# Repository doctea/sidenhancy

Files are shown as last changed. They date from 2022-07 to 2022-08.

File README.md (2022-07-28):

# sidenhancy

- Eurorack module based around the ARMSID SID chip clone
- Based around Atmega 1284p
 - oled display and rotary encoder options
 - CV inputs assignable to SID parameters
- Using [mymenu](https://github.com/doctea/mymenu) and [parameters](https://github.com/doctea/parameters)

## Hardware/PCB

- See [Wiring.md](Wiring.md) for pin wiring (unchecked / incomplete / untested!!)
- Note that **PCB FILES in pcb/ ARE NOT FINISHED, DO NOT USE THESE YET!!**

## Todo

- Parameters
  - Oscillator 1/root pitch
  - Oscillator 2 pitch
  - Oscillator 3 pitch
  - Oscillator 1 waveforms selectable 
  - Oscillator 2 waveforms selectable 
  - Oscillator 3 waveforms selectable 
  - Oscillator 1 Pulse width
  - Oscillator 2 Pulse width
  - Oscillator 3 Pulse width
  - Oscillator Detune
  - Chord
  - Filter on/off for oscillator 1
  - Filter on/off for oscillator 2
  - Filter on/off for oscillator 3
  - Filter modes LP / BP / HP
  - Filter cutoff
  - Pitch Quantization settings
- Use SID ADSR?
  - optional so module can just be used as an oscillator
  - otherwise have ADSR for each oscillator be configurable?
- ~~Menu system (using https://github.com/doctea/mymenu)~~
 - ~~Input via rotary encoder + buttons~~
   - (unreliably working with straight encoder)
   - ~~todo: i2c rotary encoder~~
 - ~~System to map assignable inputs to parameters~~
- ~~Display via i2c ss_oled~~
- CV inputs
  - Pitch
    - (working for 0-5v, quantised and not)
    - Make work with 2xPimoroni 24v ADS1015 breakouts
    - tuning / calibration functions
    - ~~three of them, one for each oscillator?~~
    - pitch modulation
    - portamento/glide
  - Filter cutoff
  - Assignable input?
- internal LFOs?
- MIDI input
- Circuit
  - Schematic
    - in progress in pcb/
  - PCB
    - in progress in pcb/
- Panel

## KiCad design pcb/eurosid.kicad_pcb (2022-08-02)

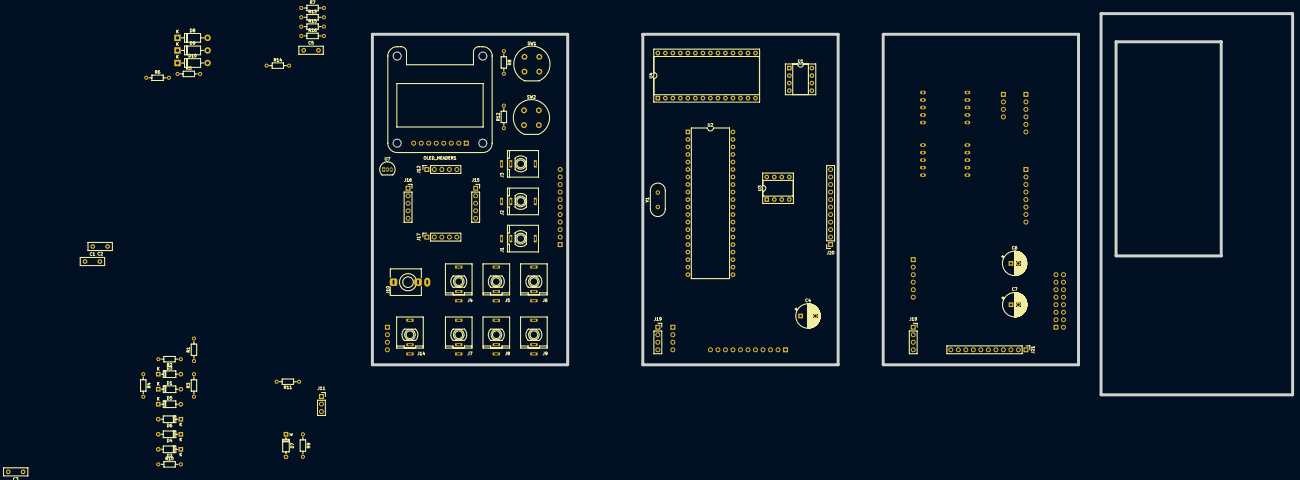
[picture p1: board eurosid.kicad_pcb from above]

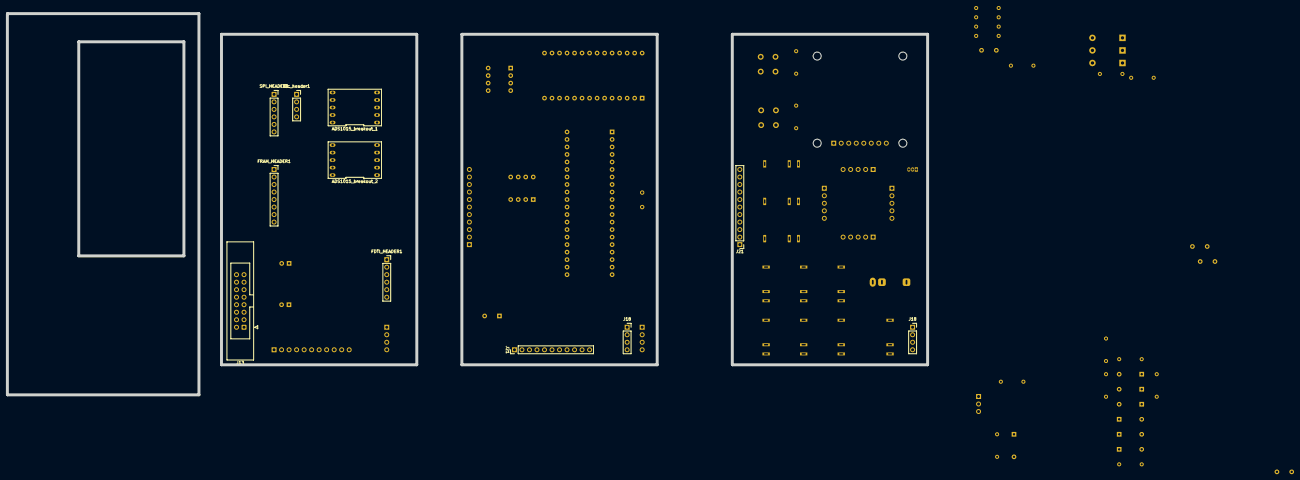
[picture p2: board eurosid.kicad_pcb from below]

Board: 2 copper layers, 311.1 x 128.9 mm, 73 parts (11 on the bottom side), 65 nets, no tracks yet.

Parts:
ADS1015_breakout_1: ADS1015_breakout
ADS1015_breakout_2: ADS1015_breakout_2; ADS1015_breakout
C1, C2: 22pf; C_Disc_D8.0mm_W2.5mm_P5.00mm
C3: 0.1uf; C_Disc_D8.0mm_W2.5mm_P5.00mm
C4: 1uf; CP_Radial_D8.0mm_P5.00mm
C5: 1nf; C_Disc_D8.0mm_W2.5mm_P5.00mm
C6, C7: CP; CP_Radial_D8.0mm_P2.50mm
D1, D2, D3, D4, D5, D6: D_Schottky; D_DO-35_SOD27_P7.62mm_Horizontal
D7: 1N4148; D_DO-35_SOD27_P7.62mm_Horizontal
D8, D9, D10: 1N5817; D_DO-41_SOD81_P10.16mm_Horizontal
FDTI_HEADER1: Conn_01x06_Female; PinSocket_1x06_P2.54mm_Vertical
FRAM_HEADER1: FRAM_Breakout_i2c_01x08; PinSocket_1x08_P2.54mm_Vertical
J1: Gate 1 In; thonkiconn_fuzzySi
J2: Gate 2 In; thonkiconn_fuzzySi
J3: Gate 3 In; thonkiconn_fuzzySi
J4: Input_Jack_A; thonkiconn_fuzzySi
J5: Input_Jack_B; thonkiconn_fuzzySi
J6: Input_Jack_C; thonkiconn_fuzzySi
J7: Input_Jack_D; thonkiconn_fuzzySi
J8: Input_Jack_E; thonkiconn_fuzzySi
J9: Input_Jack_F; thonkiconn_fuzzySi
J10: Stereo jack - MiDI TRS; Jack_3.5mm_QingPu_WQP-PJ366ST_Vertical
J11: MIDI IN Conn_01x03_Male; PinSocket_1x03_P2.54mm_Vertical
J12, J15, J16, J17: i2c encoder; PinSocket_1x05_P2.54mm_Vertical
J13: Euro power; IDC-Header_2x08_P2.54mm_Latch_Vertical
J14: Audio Out Jack; thonkiconn_fuzzySi
J18, J18#2, J19, J19#2: i2c_header_2; PinSocket_1x04_P2.54mm_Vertical
J20: Conn_01x11_Female; PinSocket_1x11_P2.54mm_Vertical
J21, J21#2, J21#3: Conn_01x11_Male; PinHeader_1x11_P2.54mm_Vertical
OLED_HEADER1: SSD1306_i2c_Oled_Conn; Adafruit_SSD1306
R1, R2, R3, R4, R5, R6, R14: 10k; R_Axial_DIN0204_L3.6mm_D1.6mm_P7.62mm_Horizontal
R7: 100k; R_Axial_DIN0204_L3.6mm_D1.6mm_P7.62mm_Horizontal
R8, R12: R; R_Axial_DIN0204_L3.6mm_D1.6mm_P7.62mm_Horizontal
R9, R11: 220R; R_Axial_DIN0204_L3.6mm_D1.6mm_P7.62mm_Horizontal
R10: 4.7K; R_Axial_DIN0204_L3.6mm_D1.6mm_P7.62mm_Horizontal
R13: 220k; R_Axial_DIN0204_L3.6mm_D1.6mm_P7.62mm_Horizontal
R15, R16: 22; R_Axial_DIN0204_L3.6mm_D1.6mm_P7.62mm_Horizontal
SPI_HEADER1: Conn_01x06_Female; PinSocket_1x06_P2.54mm_Vertical
SW1, SW2: SW_Push_Dual; Push_E-Switch_KS01Q01
U1: 6N138; DIP-8_W7.62mm_Socket
U2: ATmega1284-PU; DIP-40_W15.24mm
U3: TL072; DIP-8_W7.62mm_Socket
U4: MOS6581_6582_8580SID; DIP-28_W15.24mm_Socket
U7: L78L33_TO92; TO-92_Inline
Y1: Crystal; Crystal_HC18-U_Vertical
i2c_header1: i2c_spare; PinSocket_1x04_P2.54mm_Vertical

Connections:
3.3v: OLED_HEADER1.1, U7.1
+5V: ADS1015_breakout_1.1, ADS1015_breakout_1.6, ADS1015_breakout_2.1, ADS1015_breakout_2.6, D1.1, D3.1, D5.1, D10.1, FDTI_HEADER1.4, FRAM_HEADER1.8, J12.2, J15.2, J16.2, J17.2, J18.4, J18#2.4, J19.4, J19#2.4, R4.1, R8.2, R11.2, R12.2, SPI_HEADER1.1, U1.8, U2.10, U2.30, U2.32, U4.25, U4.28, U7.3, i2c_header1.1
+12V: C7.1, R16.2, U3.8
-12V: C6.2, R15.2
BUTTON_A: R8.1, SW1.3, U2.29
BUTTON_B: R12.1, SW2.3, U2.28
GND: ADS1015_breakout_1.5, ADS1015_breakout_1.10, ADS1015_breakout_2.5, ADS1015_breakout_2.10, C1.1, C2.2, C5.1, C6.1, C7.2, D2.2, D4.2, D6.2, FDTI_HEADER1.6, FRAM_HEADER1.7, J1.1, J1.2, J2.1, J2.2, J3.1, J3.2, J4.1, J4.2, J5.1, J5.2, J6.1, J6.2, J7.1, J7.2, J8.1, J8.2, J9.1, J9.2, J10.S, J11.1, J12.1, J13.3, J13.4, J13.5, J13.6, J13.7, J13.8, J14.1, J14.2, J15.1, J16.1, J17.1, J18.3, J18#2.3, J19.3, J19#2.3, J20.11, J21.11, J21#2.11, J21#3.11, OLED_HEADER1.2, R5.1, R6.1, R7.2, R10.1, SPI_HEADER1.2, SW1.4, SW2.4, U1.5, U2.11, U2.31, U4.14, U7.2, i2c_header1.2
Gate_1_IN: J20.2, J21.2, J21#2.2, J21#3.2, R1.2, U2.25
Gate_2_IN: J20.3, J21.3, J21#2.3, J21#3.3, R2.2, U2.26
Gate_3_IN: J20.4, J21.4, J21#2.4, J21#3.4, R3.2, U2.27
INPUT_A: ADS1015_breakout_1.7, J4.3, J20.5, J21.5, J21#2.5, J21#3.5
INPUT_B: ADS1015_breakout_1.8, J5.3, J20.6, J21.6, J21#2.6, J21#3.6
INPUT_C: ADS1015_breakout_1.9, J6.3, J20.7, J21.7, J21#2.7, J21#3.7
INPUT_D: ADS1015_breakout_2.9, J7.3, J20.8, J21.8, J21#2.8, J21#3.8
INPUT_E: ADS1015_breakout_2.8, J8.3, J20.9, J21.9, J21#2.9, J21#3.9
INPUT_F: ADS1015_breakout_2.7, J9.3, J20.10, J21.10, J21#2.10, J21#3.10
JACK_OUT: J14.3, J20.1, J21.1, J21#2.1, J21#3.1, U3.6, U3.7
MIDI_ATMEGA_RX: R11.1, U1.6, U2.14
MIDI_TX: FDTI_HEADER1.2, U2.15
unnamed: C1.2, U2.13, Y1.2
unnamed: C2.1, U2.12, Y1.1
unnamed: C3.1, R4.2, U2.9
unnamed: C3.2, FDTI_HEADER1.1
unnamed: C4.2, R7.1, U3.3
unnamed: C5.2, R14.2, U3.5
unnamed: D1.2, D2.1, J1.3, R1.1
unnamed: D3.2, D4.1, J2.3, R2.1
unnamed: D5.2, D6.1, J3.3, R3.1
unnamed: D7.1, R9.1, U1.2
unnamed: D7.2, J10.T, J11.3, U1.3
unnamed: D8.1, J13.1, J13.2
unnamed: D8.2, R15.1
unnamed: D9.1, R16.1
unnamed: D9.2, J13.9, J13.10
unnamed: D10.2, J13.11, J13.12
unnamed: J10.R, J11.2, R9.2
unnamed: J13.13, J13.14
unnamed: J13.15, J13.16
unnamed: R10.2, U1.7
unnamed: R6.2, R13.1, U3.2
unnamed: R13.2, R14.1, U3.1
SID_A0: U2.16, U4.9
SID_A1: U2.17, U4.10
SID_A2: U2.20, U4.11
SID_A3: U2.21, U4.12
SID_A4: U2.24, U4.13
SID_AUDIO_OUT: C4.1, R5.2, U4.27
SID_CLOCK: U2.19, U4.6
SID_CS: U2.2, U4.8
SID_D0: U2.33, U4.15
SID_D1: U2.34, U4.16
SID_D2: U2.35, U4.17
SID_D3: U2.36, U4.18
SID_D4: U2.37, U4.19
SID_D5: U2.38, U4.20
SID_D6: U2.39, U4.21
SID_D7: U2.40, U4.22
SID_RESET: U2.4, U4.5
SID_RW: U2.1, U4.7
SPI_MISO: SPI_HEADER1.4, U2.7
SPI_MOSI: SPI_HEADER1.5, U2.6
SPI_SCK: SPI_HEADER1.3, U2.8
SPI_SS: SPI_HEADER1.6, U2.5
i2c_SCL: ADS1015_breakout_1.3, ADS1015_breakout_2.3, FRAM_HEADER1.5, J12.4, J15.4, J16.4, J17.4, J18.2, J18#2.2, J19.2, J19#2.2, OLED_HEADER1.3, U2.22, i2c_header1.3
i2c_SDA: ADS1015_breakout_1.2, ADS1015_breakout_2.2, FRAM_HEADER1.4, J12.3, J15.3, J16.3, J17.3, J18.1, J18#2.1, J19.1, J19#2.1, OLED_HEADER1.4, U2.23, i2c_header1.4

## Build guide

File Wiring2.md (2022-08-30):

# Wiring for Sidenhancy

## ATMega 1284 pinout

	 	 SID_RW to PB0 [ 1] -      - [40] PA0 to SID_D7
		 SID_CS to PB1 [ 2] -      - [39] PA1 to SID_D6
		           PB2 [ 3] x      - [38] PA2 to SID_D5
		SID_RES to PB3 [ 4] -      - [37] PA3 to SID_D4
		    SPI SS PB4 [ 5] -      - [36] PA4 to SID_D3
		  SPI Mosi PB5 [ 6] -      - [35] PA5 to SID_D2
		  SPI Miso PB6 [ 7] -      - [34] PA6 to SID_D1
		   SPI Sck PB7 [ 8] -      - [33] PA7 to SID_D0
	FTDI 1 to 1uf to Reset [ 9] -      - [32] AREF +5v
		 +5v VCC       [10] -      - [31] GND
		 GND           [11] -      - [30] AVCC +5v
		 Xtal2         [12] -      - [29] PC7 to PIN_BUTTON_B
		 Xtal1         [13] -      - [28] PC6 to SID_A4
		 RxD0      PD0 [14] -      - [27] PC5 to SID_A3
		 TxD0      PD1 [15] -      - [26] PC4 to SID_A2
		           PD2 [16] x      - [25] PC3 to SID_A1
		           PD3 [17] x      - [24] PC2 to SID_A0
		 LED       PD4 [18] -      - [23] PC1/SDA to SDA i2c
		 SID_CLOCK PD5 [19] -      - [22] PC0/SCL to SCL i2c
		           PD6 [20] x      x [21] PD7

## SID pinout

			   CAP [ 1] x      - [28] Vdd +12V (+5v!)
		           CAP [ 2] x      - [27] Audio out
		           CAP [ 3] x      x [26] Ext. In
		           CAP [ 4] x      - [25] +5v
		PB3 to SID_RES [ 5] -      - [24] Pot X
	      PD5 to SID_CLOCK [ 6] -      - [23] Pot Y
	         PB0 to SID_RW [ 7] -      - [22] SID_D7 to PA0
		 PB1 to SID_CS [ 8] -      - [21] SID_D6 to PA1
		     PC2 to A0 [ 9] -      - [20] SID_D5 to PA2
		     PC3 to A1 [10] -      - [19] SID_D4 to PA3
		     PC4 to A2 [11] -      - [18] SID_D3 to PA4
		     PC5 to A3 [12] -      - [17] SID_D2 to PA5
		     PC6 to A4 [13] -      - [16] SID_D1 to PA6
		           GND [14] -      - [15] SID_D0 to PA7

## FTDI

	[1] -> 0.1uf cap --> resistor -> +5v
		         \__ 1284 reset pin 9
	[2] -> MIDI_TX
	[3] -> MIDI_RX
	[4] -> +5v
	[5]
	[6] -> gnd

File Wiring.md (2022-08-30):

# Wiring for Sidenhancy

## ATMega 1284 pinout

	 SID_RW to PB0 [ 1] -      - [40] PA0 to SID_D7
	 SID_CS to PB1 [ 2] -      - [39] PA1 to SID_D6
	           PB2 [ 3] -      - [38] PA2 to SID_D5
	SID_RES to PB3 [ 4] -      - [37] PA3 to SID_D4
	    SPI SS PB4 [ 5] -      - [36] PA4 to SID_D3
	  SPI Mosi PB5 [ 6] -      - [35] PA5 to SID_D2
	  SPI Miso PB6 [ 7] -      - [34] PA6 to SID_D1
	   SPI Sck PB7 [ 8] -      - [33] PA7 to SID_D0
	        Reset  [ 9] -      - [32] AREF
	 +5v VCC       [10] -      - [31] GND
	 GND           [11] -      - [30] AVCC
	 Xtal2         [12] -      - [29] PC7 to PIN_BUTTON_B
	 Xtal1         [13] -      - [28] PC6
	 RxD0      PD0 [14] -      - [27] PC5
	 TxD0      PD1 [15] -      - [26] PC4
	 SID_A0 to PD2 [16] -      - [25] PC3
	 SID_A1 to PD3 [17] -      - [24] PC2 to SID_A4
	 LED       PD4 [18] -      - [23] PC1/SDA to SDA i2c
	 SID_CLOCK PD5 [19] -      - [22] PC0/SCL to SCL i2c
	 SID_A2 to PD6 [20] -      - [21] PD7 to SID_A3

## SID pinout

           CAP [ 1] -      - [28] Vdd +12V (+5v!)
           CAP [ 2] -      - [27] Audio out
           CAP [ 3] -      - [26] Ext. In
           CAP [ 4] -      - [25] +5v
       SID_RES [ 5] -      - [24] Pot X
     SID_CLOCK [ 6] -      - [23] Pot Y
        SID_RW [ 7] -      - [22] SID_D7
        SID_CS [ 8] -      - [21] SID_D6
            A0 [ 9] -      - [20] SID_D5
            A1 [10] -      - [19] SID_D4
            A2 [11] -      - [18] SID_D3
            A3 [12] -      - [17] SID_D2
            A4 [13] -      - [16] SID_D1
           GND [14] -      - [15] SID_D0

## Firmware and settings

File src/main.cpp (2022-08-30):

#include "Arduino.h"

#include "Config.h"

#include "sid6581.h"

#include "sid_parameters.h"

#ifdef ENABLE_STORAGE
  #include "storage.h"
#endif

#include "ads.h"

//#include "display_ss.h"
#ifdef ENABLE_SCREEN
  #include "i2cencoder.h"
  //#include "io.h"
  #include "mymenu.h"
  //#include "menu_io.h"
  void setup_menu();
#endif

//#include "mtof.h"

SID6581 sid = SID6581();

void setup() {
    Serial.begin(115200);
    Serial.println(F("\n\n\n======================= sidenhancy starting up! >>>>>>>>>>>>>>>>>>>>>\n"));
    #ifdef WAIT_FOR_SERIAL
      while (!Serial);
    #endif
    // todo: MIDI on Serial1

    pinMode(PIN_LED, OUTPUT);

    digitalWrite(PIN_LED, HIGH);

    Serial.println(F("\tInitialising sid.."));
    sid.setup();
    /*sid.voice[0].pulseOn();
    sid.voice[1].pulseOn();
    sid.voice[2].pulseOn();
    sid.voice[0].sawOn();
    sid.voice[2].sawOn();*/
    Serial.println(F("\tsid initialised!"));

    //setup_ads();
    setup_voltage_sources();

    #ifdef ENABLE_SCREEN
      Serial.println(F("\tSetting up display.."));
      setup_menu();
      //setup_display();
      Serial.println(F("\tFinished initialising display!"));
      //tft_print("hello", 0, 0);
    #endif
    
    Serial.println(F("Setting up parameters.."));
    setup_parameters();
    Serial.println(F("Parameter setup done!"));

    #ifdef ENABLE_STORAGE
      setup_storage();
    #endif

    //save_parameter_settings(&available_parameters, &available_inputs, DEFAULT_SLOT);
    #ifdef LOAD_PARAMETER_SETTINGS
      load_parameter_settings(&available_parameters, &available_inputs, 0); // restore previous settings
    #endif

    #ifdef ENABLE_SCREEN
      setup_parameter_menu();
    #endif

    sid.allGateOn();  // turn on all gates so that we can use this like an oscillator

    Serial.println(F("exiting setup()\n\n"));
}

void note_loop() {
    //sid.test_tones();
    Serial.println(F("Looped!")); Serial.flush();
    static int value = 33;

    //return;

    if (value>=80)
      value = 33;

    Serial.printf(F("Sounding chord %i...\n"), value); Serial.flush();

    static int a,d,s,r;

    //seed(analogRead(A1));
    a = random(15);
    d = random(15);
    s = random(15);
    r = random(15);
    sid.voice[0].setADSR((a+d)%15,(d+s)%15,(s+r)%15,(r+a)%15);
    sid.voice[1].setADSR((d+d)%15,(a+s)%15,(r+r)%15,(s+a)%15);
    sid.voice[2].setADSR((a+r)%15,(d+r)%15,(s+a)%15,(r+d)%15);
    /*sid.voice[1].setADSR(a,d,s,r);
    sid.voice[2].setADSR((d+d)%15,(a+s)%15,(r+r)%15,(s+a)%15);
    sid.voice[3].setADSR((a+r)%15,(d+r)%15,(s+a)%15,(r+d)%15);*/

    digitalWrite(PIN_LED, HIGH);
    sid.playNote(0, value);
    sid.playNote(1, value+4);
    sid.playNote(2, value+7);
    delay(1000);

    digitalWrite(PIN_LED, LOW);
    Serial.printf(F("Stopping note %i.\n"), value);
    sid.stopNote(0);
    sid.stopNote(1);
    sid.stopNote(2);
    delay(3000);

    value += 1;
    //sid.test_tones();
}

void led_on() {
  digitalWrite(PIN_LED, HIGH);
}
void led_off() {
  digitalWrite(PIN_LED, LOW);
}

void loop() {
  bool debug = true;
  static int mode = 0;
  static bool paused = false;

  if (debug) {  Serial.println(F("Start loop()!")); Serial.flush(); }

  if (debug) { Serial.println(F("updating inputs()..")); Serial.flush(); }
  #ifdef ENABLE_SCREEN
    menu->update_inputs();
    update_encoder();
  #endif

  update_parameters();

  #ifdef ENABLE_SCREEN
    static unsigned long last_drawn = millis();
    if (millis() - last_drawn > 50) {
      if (debug) { Serial.println(F("updating display()!"));  Serial.flush(); }
      menu->display();
      if (debug) { Serial.println(F("done display()!"));      Serial.flush(); }
      last_drawn = millis();
    }
  #endif

  //static unsigned long last_milli = 0;
  //if (millis()!=last_milli) {
    update_voltage_sources();
    //last_milli = millis();
  //}

  while(Serial.available()) {
    char i = Serial.read();
    Serial.println(i);
    /*if (i=='d') {
      tft_print("test?", random(40), random(10));
    }*/
    if (i=='#') {
      sid.printStatus();
      return;
    }
    if (i=='P') {
      paused = !paused;
      if (paused) Serial.println(F("Paused"));
      return;
    }
    if (i=='S') {
      if (sid.resonance==0)
        sid.setResonance((byte)MAX_RESONANCE);
      else
        sid.setResonance((byte)0);
      return;
    }
    if (i=='F') {
      Serial.println(F("Setting filtervoices")); // and random oscmask");
      for (int i = 0 ; i < 3 ; i++) {
        //sid.voice[i].setOscMask(random(15));
        sid.setFilterVoice(i,false);
      }
      sid.updateFilterVoice();
      return;
    }
    if (i=='f') {
      Serial.println(F("Unsetting filterVoice"));
      for (int i = 0 ; i < 3 ; i++) {
        sid.unsetFilterVoice(i,false);
      }
      sid.updateFilterVoice();
      return;
    }
    if (i=='G') {
      Serial.println("Setting random filter types"); // and random oscmask");
      sid.setFilterType(random(15)<<4,false);
      sid.unsetFilterType(random(15)<<4);
      /*for (int i = 0 ; i < 3 ; i++) {
        //sid.voice[i].setOscMask(random(15));
        sid.setFilterType(i,false);
      }
      sid.updateFilterVoice();
      return;*/
    }
    if (i=='f') {
      Serial.println("Unsetting filter types");
      for (int i = 0 ; i < 4 ; i++) {
        sid.unsetFilterType(1 << i,false);
      }
      sid.updateFilterType();
      return;
    }
    if (i=='Q') {
      sid.setResonance((byte)15);
      for (int i = MAX_CUTOFF ; i > 0 ; i--) {
        sid.setCutoff((uint16_t)i);
        //Serial.printf("Cutoff=%i\n",i);
        //delay(1);
      }
    }
    if (i=='M') {
      static int oscMask = 1;
      static int oscNum = 0;
      sid.voice[oscNum].unsetOscMask(oscMask<<4);
      oscMask = oscMask << 1;
      if (oscMask>15)
        oscMask = 1;
      oscNum++; oscNum %= 3;
      Serial.printf(F("setting osc %i to oscMask %i\n"), oscNum, oscMask);
      sid.voice[oscNum].setOscMask(oscMask<<4);
      return;
    }
    if(i=='+') {
      if (sid.cutoff>=MAX_CUTOFF) sid.cutoff = MAX_CUTOFF/2;
      sid.setCutoff((uint16_t)(sid.getCutoff()+1));
      return;
    }
    if(i=='-') {
      if (sid.cutoff<=0) sid.cutoff = MAX_CUTOFF;
      sid.setCutoff((uint16_t)(sid.getCutoff()-1));
      return;
    }
    if (i=='U') {
      bool orig_debug = debug_sid;
      Serial.println(F("calling sid->updateAll()"));
      debug_sid = true;

      sid.updateAll();
      debug_sid = orig_debug;
      Serial.println(F("---"));
    }
    if (i=='_') {
      debug_sid = !debug_sid;
      Serial.printf(F("debug set to %i\n------\n"), debug_sid);
      return;
    }
    if (i=='E') {
      Serial.println(F("test_tones:"));
      //hw.write(23,0xF1); //1ch filter
      //hw.write(24,0x0F); //volume
      /*sid.setCutoff(MAX_CUTOFF);
      sid.setFilterVoice(0);
      sid.setResonance(0);
      sid.unsetFilterType(0x0F);
      sid.setFilterType(filter_lowpass);*/
      //sid.updateAll();
      sid.test_tones();
      Serial.println(F("finished test_tones!"));
      return;
    }
    if (i=='1') sid.voice[0].gateOff();
    if (i=='!') sid.voice[0].gateOn();
    if (i=='2') sid.voice[1].gateOff();
    if (i=='"') sid.voice[1].gateOn();
    if (i=='3') sid.voice[2].gateOff();
    if (i=='4') sid.voice[2].gateOn();

    #ifdef ENABLE_SCREEN
      if (i=='0') setup_encoder();
    #endif

    if (i=='R') {
      Serial.println(F("Resetting.."));
      sid.resetChip();
      sid.voice[0].setADSR(0,0,15,5);
      sid.voice[1].setADSR(0,0,15,5);
      sid.voice[2].setADSR(0,0,15,5);
      sid.voice[0].setFrequency(MAX_FREQ/2,true);
      sid.voice[1].setFrequency(MAX_FREQ/2,true);
      sid.voice[2].setFrequency(MAX_FREQ/2,true);
      //sid.unsetFilterType(triMask | sawMask | pulseMask);
      sid.unsetFilterVoice(0,false);
      sid.unsetFilterVoice(1,false);
      sid.unsetFilterVoice(2,false);
      sid.unsetFilterVoice(3,false);
      sid.updateAll();
      led_on();
      sid.voice[0].gateOn();
      sid.voice[1].gateOn();
      sid.voice[2].gateOn();
      delay(1000);
      led_off();
      sid.voice[0].gateOff();
      sid.voice[1].gateOff();
      sid.voice[2].gateOff();
      delay(1000);
      Serial.println(F("Reset and should have beeped?"));
      return;
    }
    if (i=='D') {
      mode = 0;
      Serial.println(F("Switching to Direct mode"));
    } else if (i=='T') {
      mode = 1;
      Serial.println(F("Switching to Table mode"));
    } else if (i=='N') {
      mode = 2;
      Serial.println(F("Switching to Note loop mode"));
    }
    if (i=='K') {
      sid.voice[0].stopNote();
      sid.voice[1].stopNote();
      sid.voice[2].stopNote();
    } else if (i=='k') {
      sid.voice[0].gateOn();
      sid.voice[1].gateOn();
      sid.voice[2].gateOn();
    }
  }

  if (paused) return;
}

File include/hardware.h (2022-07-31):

#ifndef HARDWARE__INCLUDED
#define HARDWARE__INCLUDED

// code to actually talk to the SID chip using the MCU's ports etc
// in theory this is where we'd replace it with shift registers et al

#include <Arduino.h>

#include "sidspec.h"

#define CHECK_BIT(var,pos) ((var) & (pos))

#define BYTE_TO_BINARY_PATTERN "%c%c%c%c%c%c%c%c"
#define BYTE_TO_BINARY(byte)  \
  (byte & 0x80 ? '1' : '0'), \
  (byte & 0x40 ? '1' : '0'), \
  (byte & 0x20 ? '1' : '0'), \
  (byte & 0x10 ? '1' : '0'), \
  (byte & 0x08 ? '1' : '0'), \
  (byte & 0x04 ? '1' : '0'), \
  (byte & 0x02 ? '1' : '0'), \
  (byte & 0x01 ? '1' : '0') 

extern bool debug_sid;

// implement stuff for actually reading/writing to the chip - so can "easily" rewire it
class Socket {
    public:

    // for tracking what has previously been written to this chip so we don't waste time duplicating data
    byte last_written[sizeof(sidmap)];

    bool debug = false;

    // use PORTA for data bus
    #define SID6581_PIN_D0  PIN_PA7
    #define SID6581_PIN_D1  PIN_PA6
    #define SID6581_PIN_D2  PIN_PA5
    #define SID6581_PIN_D3  PIN_PA4
    #define SID6581_PIN_D4  PIN_PA3
    #define SID6581_PIN_D5  PIN_PA2
    #define SID6581_PIN_D6  PIN_PA1
    #define SID6581_PIN_D7  PIN_PA0

    // use sort of PORTD and one pin of PORTC for address bus
    // skip PD4 + PD5 so that they can be use as oscillator pinouts
    #define SID6581_PIN_A0  PIN_PD2
    #define SID6581_PIN_A1  PIN_PD3
    #define SID6581_PIN_A2  PIN_PD6
    #define SID6581_PIN_A3  PIN_PD7
    #define SID6581_PIN_A4  PIN_PC2

    // SID control pins
    #define SID6581_PIN_RESET   PIN_PB3
    #define SID6581_PIN_RW      PIN_PB0
    #define SID6581_PIN_SEL     PIN_PB1

    #define SID6581_PIN_CLOCK   PIN_PD5


    void setup() {
        pinMode( SID6581_PIN_D0, OUTPUT );
        pinMode( SID6581_PIN_D1, OUTPUT );
        pinMode( SID6581_PIN_D2, OUTPUT );
        pinMode( SID6581_PIN_D3, OUTPUT );
        pinMode( SID6581_PIN_D4, OUTPUT );
        pinMode( SID6581_PIN_D5, OUTPUT );
        pinMode( SID6581_PIN_D6, OUTPUT );
        pinMode( SID6581_PIN_D7, OUTPUT );
        
        pinMode( SID6581_PIN_A0, OUTPUT );
        pinMode( SID6581_PIN_A1, OUTPUT );
        pinMode( SID6581_PIN_A2, OUTPUT );
        pinMode( SID6581_PIN_A3, OUTPUT );
        pinMode( SID6581_PIN_A4, OUTPUT );
        
        pinMode( SID6581_PIN_RESET, OUTPUT );
        pinMode( SID6581_PIN_RW, OUTPUT );
        pinMode( SID6581_PIN_SEL, OUTPUT );

        pinMode( SID6581_PIN_CLOCK, OUTPUT );

        setupClock();

        resetChip();
    }

    void setupClock() {
        pinMode( SID6581_PIN_CLOCK, OUTPUT );
        TCCR1A = 0;
        TCCR1B = 0;
        TCNT1 = 0;
        OCR1A = 7;   // toggle after counting to 8
        TCCR1A |= (1 << COM1A0);   // Toggle OC1A on Compare Match.
        TCCR1B |= (1 << WGM12);    // CTC mode
        TCCR1B |= (1 << CS10);     // clock on, no pre-scaler

        delayMicroseconds(1);
    }

    void waitCycle(void) {
        /*uint8_t foo = digitalRead( SID6581_PIN_TIMER );

        while( foo != HIGH ) {
            Serial.println("Delay1");
            foo = digitalRead( SID6581_PIN_TIMER );
        }
        
        foo = digitalRead( SID6581_PIN_TIMER );
        while( foo == HIGH ) {
            Serial.println("Delay2");    
            foo = digitalRead( SID6581_PIN_TIMER );
        }*/
        delayMicroseconds(2);
    }

    // set the SID address bus pins
    void setAddress(byte what) {
        digitalWrite( SID6581_PIN_A0, CHECK_BIT(what,1)?HIGH:LOW );
        digitalWrite( SID6581_PIN_A1, CHECK_BIT(what,2)?HIGH:LOW );
        digitalWrite( SID6581_PIN_A2, CHECK_BIT(what,4)?HIGH:LOW );
        digitalWrite( SID6581_PIN_A3, CHECK_BIT(what,8)?HIGH:LOW );
        digitalWrite( SID6581_PIN_A4, CHECK_BIT(what,16)?HIGH:LOW );
    }

    // set the SID data bus pins
    void setData(byte what) {
        digitalWrite( SID6581_PIN_D0, CHECK_BIT(what,1)?HIGH:LOW );
        digitalWrite( SID6581_PIN_D1, CHECK_BIT(what,2)?HIGH:LOW );
        digitalWrite( SID6581_PIN_D2, CHECK_BIT(what,4)?HIGH:LOW );
        digitalWrite( SID6581_PIN_D3, CHECK_BIT(what,8)?HIGH:LOW );
        digitalWrite( SID6581_PIN_D4, CHECK_BIT(what,16)?HIGH:LOW );
        digitalWrite( SID6581_PIN_D5, CHECK_BIT(what,32)?HIGH:LOW );
        digitalWrite( SID6581_PIN_D6, CHECK_BIT(what,64)?HIGH:LOW );
        digitalWrite( SID6581_PIN_D7, CHECK_BIT(what,128)?HIGH:LOW );
    }
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

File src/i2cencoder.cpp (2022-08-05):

#include <Wire.h>
#include <i2cEncoderLibV2.h>

#include "mymenu.h"

const int IntPin = PIN_PC4;

i2cEncoderLibV2 Encoder(0x01); /* A0 is soldered */

//Callback when the CVAL is incremented
void encoder_increment(i2cEncoderLibV2* obj) {
  menu->knob_left();
  Serial.print(F("Increment: "));
  Serial.println(Encoder.readCounterByte());
}

//Callback when the CVAL is decremented
void encoder_decrement(i2cEncoderLibV2* obj) {
  menu->knob_right();
  Serial.print(F("Decrement: "));
  Serial.println(Encoder.readCounterByte());
}

//Callback when CVAL reach MAX
void encoder_max(i2cEncoderLibV2* obj) {
  Serial.print(F("Maximum threshold: "));
  Serial.println(Encoder.readCounterByte());
}

//Callback when CVAL reach MIN
void encoder_min(i2cEncoderLibV2* obj) {
  Serial.print(F("Minimum threshold: "));
  Serial.println(Encoder.readCounterByte());
}

//Callback when the encoder is pushed
void encoder_push(i2cEncoderLibV2* obj) {
  menu->button_select();
  Serial.println(F("Encoder is pushed!"));
}

//Callback when the encoder is released
void encoder_released(i2cEncoderLibV2* obj) {
  Serial.println(F("Encoder is released"));
}

//Callback when the encoder is double pushed
void encoder_double_push(i2cEncoderLibV2* obj) {
  Serial.println(F("Encoder is double pushed!"));
}

void setup_encoder() {
  Serial.println("setup_encoder..."); Serial.flush();

  pinMode(IntPin, INPUT);

  Serial.println("\tEncoder.reset().."); Serial.flush();
  Encoder.reset();

  Serial.println("\tEncoder.begin().."); Serial.flush();
  Encoder.begin(
      i2cEncoderLibV2::INT_DATA | i2cEncoderLibV2::WRAP_ENABLE
      | i2cEncoderLibV2::DIRE_LEFT | i2cEncoderLibV2::IPUP_ENABLE
      | i2cEncoderLibV2::RMOD_X1 | i2cEncoderLibV2::RGB_ENCODER);

  Serial.println("\tEncoder.writeStuff..."); Serial.flush();
  Encoder.writeCounter((int32_t) 0); /* Reset the counter value */
  //Encoder.writeMax((int32_t) 10); /* Set the maximum threshold*/
  //Encoder.writeMin((int32_t) - 10); /* Set the minimum threshold */
  Encoder.writeStep((int32_t) 1); /* Set the step to 1*/
  Encoder.writeInterruptConfig(0xff); /* Enable all the interrupt */
  Encoder.writeAntibouncingPeriod(20); /* Set an anti-bouncing of 200ms */
  //Encoder.writeDoublePushPeriod(50); /*Set a period for the double push of 500ms */

  // Definition of the events
  Encoder.onIncrement = encoder_increment;
  Encoder.onDecrement = encoder_decrement;
  Encoder.onMax = encoder_max;
  Encoder.onMin = encoder_min;
  Encoder.onButtonPush = encoder_push;
  Encoder.onButtonRelease = encoder_released;
  Encoder.onButtonDoublePush = encoder_double_push;

  /* Enable the I2C Encoder V2 interrupts according to the previus attached callback */
  Serial.println("\tEncoder.autoconfigInterrupt().."); Serial.flush();
  Encoder.autoconfigInterrupt();
  Serial.println("... finished setup_encoder"); Serial.flush();
}

void update_encoder() {
    if (digitalRead(IntPin) == LOW) {
      /* Check the status of the encoder and call the callback */
      Encoder.updateStatus();
    }
}

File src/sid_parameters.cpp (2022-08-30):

#include "sid6581.h"

#include "Config.h"

#include "ads.h"

#include "voltage_sources/VoltageSource.h"
#include "voltage_sources/ADSVoltageSource.h"
#include "voltage_sources/ADS24vVoltageSource.h"

#include "parameters/FrequencyParameter.h"
#include "parameters/ToggleParameter.h"

//#include "ParameterInput.h"
#include "parameter_inputs/VoltageParameterInput.h"

#include "mymenu.h"
#include "mymenu_items/ParameterMenuItems.h"
#include "mymenu_items/ToggleMenuItems.h"

#include "LinkedList.h"

#include "ADS1X15.h"

LinkedList<VoltageSourceBase*> voltage_sources = LinkedList<VoltageSourceBase*> ();

/////// PARAMETER INPUTS & VOLTAGE SOURCES

#ifdef ENABLE_ADS_24V
    #define MAX_INPUT_VOLTAGE_24V 10.0
    ADS1015 ADS_OBJECT_24V(0x49);
    ADS24vVoltageSource<ADS1015> voltage_source_1_channel_0 = ADS24vVoltageSource<ADS1015>(&ADS_OBJECT_24V, 0, MAX_INPUT_VOLTAGE_24V);
    ADS24vVoltageSource<ADS1015> voltage_source_1_channel_1 = ADS24vVoltageSource<ADS1015>(&ADS_OBJECT_24V, 1, MAX_INPUT_VOLTAGE_24V);
    ADS24vVoltageSource<ADS1015> voltage_source_1_channel_2 = ADS24vVoltageSource<ADS1015>(&ADS_OBJECT_24V, 2, MAX_INPUT_VOLTAGE_24V);
#endif

#ifdef ENABLE_ADS_x48
    #define MAX_INPUT_VOLTAGE_x48 5.0
    ADS1115 ADS_OBJECT_x48(0x48);
    ADSVoltageSource<ADS1115> voltage_source_2_channel_0 = ADSVoltageSource<ADS1115>(&ADS_OBJECT_x48, 0, MAX_INPUT_VOLTAGE_x48);
    ADSVoltageSource<ADS1115> voltage_source_2_channel_1 = ADSVoltageSource<ADS1115>(&ADS_OBJECT_x48, 1, MAX_INPUT_VOLTAGE_x48);
    ADSVoltageSource<ADS1115> voltage_source_2_channel_2 = ADSVoltageSource<ADS1115>(&ADS_OBJECT_x48, 2, MAX_INPUT_VOLTAGE_x48);
    ADSVoltageSource<ADS1115> voltage_source_2_channel_3 = ADSVoltageSource<ADS1115>(&ADS_OBJECT_x48, 3, MAX_INPUT_VOLTAGE_x48);
#endif

void setup_voltage_sources() {
    Serial.println("setup_voltage_sources...");
    #ifdef ENABLE_ADS_x48
        Serial.println("Beginning ADS_x48..");
        ADS_OBJECT_x48.begin();
        ADS_OBJECT_x48.setGain(0);
        voltage_sources.add(&voltage_source_2_channel_0);
        voltage_sources.add(&voltage_source_2_channel_1);
        voltage_sources.add(&voltage_source_2_channel_2);
        voltage_sources.add(&voltage_source_2_channel_3);
        Serial.println("..done ADS_x48");
    #endif
    
    #ifdef ENABLE_ADS_24V
        Serial.println("Beginning ADS_24V..");
        ADS_OBJECT_24V.begin();
        ADS_OBJECT_24V.setGain(2);
        voltage_sources.add(&voltage_source_1_channel_0);
        voltage_sources.add(&voltage_source_1_channel_1);
        voltage_sources.add(&voltage_source_1_channel_2);
        voltage_source_1_channel_0.correction_value_1 = 1180.0;
        //voltage_source_1_channel_0.debug = true;
        //voltage_source_1_channel_1.debug = true;
        //voltage_source_1_channel_2.debug = true;
        Serial.println("..done ADS_24V");
    #endif
    Serial.println("done setup_voltage_sources!");
}

void update_voltage_sources() {
    // round robin reading so they get a chance to settle in between adc reads?
    int size = voltage_sources.size();
    if (size==0) return;

    static int last_read = 0;
    voltage_sources.get(last_read)->update();
    last_read++;
    
    if (last_read>=size)
        last_read = 0;

    voltage_sources.get(last_read)->update();   // pre-read the next one so it has a chance to settle?


    /*for (int i = 0 ; i < voltage_sources.size() ; i++) {
        voltage_sources.get(i)->update();
    }*/
}

// ParameterInputs, ie wrappers around input mechanism, assignable to a Parameter
LinkedList<BaseParameterInput*> available_inputs            = LinkedList<BaseParameterInput*>();


// Parameters, ie wrappers around destination object
LinkedList<DataParameter*>      available_parameters    = LinkedList<DataParameter*>();

DataParameter       param_none                              = DataParameter((char*)"None");
FrequencyParameter  param_overall_pitch                     = FrequencyParameter<SID6581,double> ((char*)"Overall pitch", &sid, 0.0, &SID6581::setAllFrequency);
Parameter           param_overall_pulsewidth_modulation     = Parameter<SID6581,double> ((char*)"Overall PW Mod", &sid, 0.0, &SID6581::modulateAllPulseWidths);
Parameter           param_overall_pitch_modulation          = Parameter<SID6581,double> ((char*)"Overall Pitch Mod", &sid, 0.0, &SID6581::modulateAllPitches);

Parameter           param_filter_cutoff                     = Parameter<SID6581,double> ((char*)"Filter cutoff", &sid, 0.0, &SID6581::setCutoff);
Parameter           param_filter_resonance                  = Parameter<SID6581,double> ((char*)"Filter res", &sid, 0.0, &SID6581::setResonanceD);
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

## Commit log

2022-05-20 first commit of proof of concept with CV control of pitch
2022-05-22 screen stuff moved to external library..! compiles, but doesn't run / crashes
    [Config.h, hardware.h, main.cpp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]
2022-05-22 compiles, runs, doesnt crash!
    [main.cpp, menu.cpp]
2022-05-22 fixed encoder pinout ..
    [Config.h]
2022-05-22 filter cutoff control via menu
2022-05-28 this build doesnt crash (doesnt work properly either tho, can only read from first ADC?)
    [main.cpp, menu.cpp, sid6581.h]
2022-05-29 pulse width modulation on second cv input! seem to be running outta RAM though, had to wrap all strings with F()s to stop it from crashing when added more menu items
    [hardware.h, main.cpp, menu.cpp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]
2022-06-05 ... with i2cencoder, but very unreliable, going to revert to previous versions to try and and work out why its crashing on start so frequently now
    [Config.h, i2cencoder.cpp, main.cpp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]
2022-06-05 seems to not crashy anymore? some weirdness going on with menu display tho
    [i2cencoder.cpp, main.cpp, sid6581.h]
2022-06-06 builds against parameters library (but probably does not work)
    [sid_parameters.cpp]
2022-06-06 pitch is working with corresponding version of parameter library!
2022-06-06 powerloss commit?
2022-06-06 alright, multiple parameters added with relative ease, inverting etc
    [main.cpp, menu.cpp, sid6581.h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]
2022-06-08 minor move of menu display mode setting before adding menu items - in case we need to know the mode at the point of adding in future
2022-06-11 don't specify types of Parameter when creating ParameterInputs; vibrato kinda working
    [main.cpp, sid6581.h, sid_parameters.cpp]
2022-06-11 pitch tracking working again
2022-06-12 sort of working toggle items for enabling waveforms, but not quite working. significant changes so doing in separate branch as may want to revert
    [main.cpp, sid6581.h, sid_parameters.cpp]
2022-06-13 saves parameter info to fram; doesn't load it back in yet tho
    [main.cpp, sid_parameters.cpp]
2022-07-09 filters and osc modes now largely work from menus, still some oddities though (noise osc worked once but not since?)
    [main.cpp, sid6581.h, sid_parameters.cpp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]
2022-07-09 use refactored VoltageSource stuff
2022-07-09 remove some old cruft, configurable option to restore parameterinput inverted+unipolar setting
    [Config.h, main.cpp, storage.cpp]
2022-07-09 config to enable/disable two ADCs, dynamic creation of ParameterInputs from VoltageSources
2022-07-27 starting to document wiring...
2022-07-28 commit progress on schematic
    [eurosid.kicad_pcb, eurosid.sch]
2022-07-31 tracked hardware
    [eurosid.kicad_pcb, eurosid.sch, file6329C7FA.sch]
2022-07-31 compiles against v0.0.3 of parameters library; but my i2c has stopped working(?) so dont know if working properly..
2022-08-02 slightly updated
    [eurosid.kicad_pcb]
2022-08-05 better separation of i2c configs so that easier to debug. change correction values to be more accurate to current situation
    [Config.h, i2cencoder.cpp, main.cpp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]
2022-08-30 moved Wiring.md into correct place; this version compiles and runs on my breadboard..
    [Config.h, main.cpp, sid_parameters.cpp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]
